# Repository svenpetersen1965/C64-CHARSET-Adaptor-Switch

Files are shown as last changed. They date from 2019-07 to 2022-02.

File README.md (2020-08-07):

# C64-CHARSET-Adaptor-Switch
An Adaptor for the Character ROM of the Commodore C64 (2332 = 4k). It accepts EPROMs of the types 27C64, 27C128, 27C256 and 27C512.

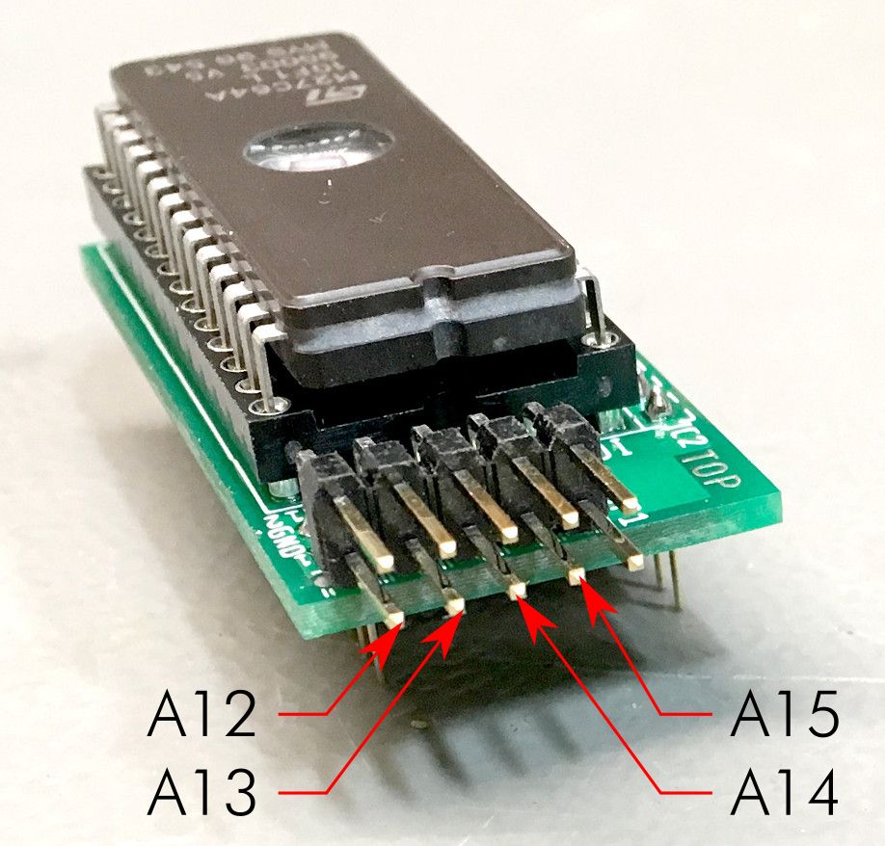
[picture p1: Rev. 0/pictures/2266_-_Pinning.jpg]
C64 charset adaptor/switch


The charcter sets can be selected by jumper or by a microcontroller circuit like an arduino or the keyboard controlled kernal switch: https://github.com/svenpetersen1965/C64-Keyboard-Controlled-Kernal-Switch
# Calculation of the BOM v0.0 prices
The prices were calculated June 9th, 2020. The total costs for the components and PCB are 3.80€, which does not include and shipping fees.

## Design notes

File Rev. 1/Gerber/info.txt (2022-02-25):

      
       Board: C64_CHARSETSw_4k
       Rev.:  1
  
       Files:
       ======
  
       All Gerber files are generated in extended gerber format (RS274X)
       *.TOP        : Film top copper
       *.BOT        :  -"- bottom copper
       *.STC        :  -"- top soldermask 
       *.STS        :  -"- bottom soldermask
       *.PLC        :  -"- silk screen top
       *.PLS        :  -"- silk screen bottom
       *.CRC        :  -"- cream top
       *.DK         : Drills plated Through (Excellon)
       *.NDK        : Drills not plated Through (Excellon)
       *.OUT        : Board outline

       Board Size:
       ===========
       Length     :   45.0 mm
       Width      :   22.0 mm
       Thickness  :   1.6 mm
       Material   :   FR 4
       Copper     :   35 um
       Surface    :   HASL
       
       Remarks:
       ========

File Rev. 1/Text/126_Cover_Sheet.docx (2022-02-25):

Project Documentation

C64 CHARSET-Adaptor/Switch

Project number: 126

Revision: 1

Date: 15.02.2021


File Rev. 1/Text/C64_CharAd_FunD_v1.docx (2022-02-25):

C64 CHARSET-Adaptor/Switch Rev. 1

Functional Description

IC2 is not an actual IC, these are the precision round pin contacts on the solder side of the module, that fit into the Character ROM socket on the C64 mainboard. The signals A0…A11 are connected to the address bus, D0…D7 are connected to the data bus. The chip select signal is connected to the C64 signal, which selects the character rom at the addresses 0xD000 - 0xDFFF.

IC1 is the EPROM, which is here represented by a 27C512 (other types are possible, see the document 126-6-01-**/Module Description).

The chip select signal is connected to pin 22, the enable signal is permanently LOW.

R1 – R4 are pull-up resistors. The desired character set can be either jumpered at JP1 or selected by a micro controller, which is connected to the same pin header.

C64_CharAd_FunD_v1.docx 25.02.2022 10:58 Drafted by Sven Petersen Page 2 of 2 Doc.-No.: 000-6-00-00

C64_CharAd_FunD_v1.docx 25.02.2022 10:58 Drafted by Sven Petersen Page 1 of 1 Doc.-No.: 126-6-02-01

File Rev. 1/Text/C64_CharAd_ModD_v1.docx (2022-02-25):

C64 CHARSET-Adaptor/Switch Rev. 1

Module Description

# Introduction

The board serves for adapting the CHARACTER ROM U5 (type 2332) to a 27C512 (or 27C256, 27C128, 27C64) EPROM. The pin out of both ICs are slightly different and need adaptation. Furthermore, it allows to access (up to 16) different character sets, which can be selected via the pin-header on the module.

The CHARSET-Adaptor/Switch is suitable to work together with the Keyboard Controlled Kernal Switch (Project Number 128).

This pin-header is connected in a way, that the selection can either be accomplished with standard 2.54mm jumper bridges, DIP-switches, hex-encoding switches or a microcontroller like an Arduino etc.

Signal | Pin | Pin | Signal
A12 | 1 | 2 | GND
A13 | 3 | 4 | GND
A14 | 5 | 6 | GND
A15 | 7 | 8 | GND
+5V | 9 | 10 | n.c.

Table 1: Jumper (JP1) for Bank Selection

The +5V pins are to provide supply voltage to a microcontroller.


Figure 1: Address pins of JP1

# Bank Selection

The desired CHARACTER SET is selected at JP1. For the pinout refer to Table 1. The jumper is installed (vertically) in a way, that it connects the address line with the GND potential.

A15 | A14 | A13 | A12 | 4k Block | | Addr. Offset
set | set | set | set | | #0 | 0x0000
set | set | set | open | | #1 | 0x1000
set | set | open | set | | #2 | 0x2000
set | set | open | open | | #3 | 0x3000
set | open | set | set | | #4 | 0x4000
set | open | set | open | | #5 | 0x5000
set | open | open | set | | #6 | 0x6000
set | open | open | open | | #7 | 0x7000
open | set | set | set | | #8 | 0x8000
open | set | set | open | | #9 | 0x9000
open | set | open | set | | #10 | 0xA000
open | set | open | open | | #11 | 0xB000
open | open | set | set | | #12 | 0xC000
open | open | set | open | | #13 | 0xD000
open | open | open | set | | #14 | 0xE000
open | open | open | open | | #15 | 0xF000

Table 2: Selection of EPROM memory blocks

A set jumper corresponds to a LOW level (binary 0), an open jumper to a HIGH level. Do not confuse the C64 memory address and the EPROM memory address. They have the address Bit A0 to A11 in common, but the rest is different. Each of the 4k blocks appears between address $D000 and $DFFF of the C64.

# Dimensions

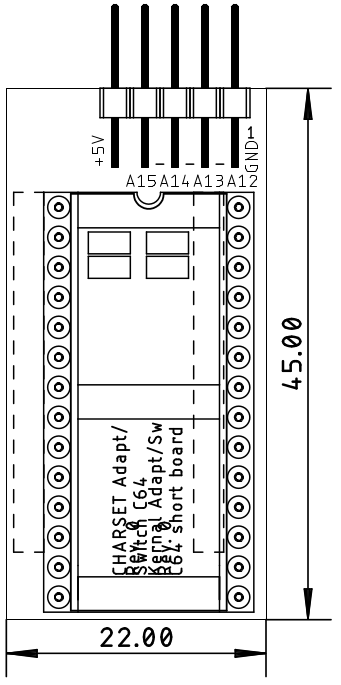
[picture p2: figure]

Figure 2: Dimensions of the Character ROM Adaptor/Switch

# Compatibility of EPROMs

Although a 27C512 type EPROM is recommended, other types of EPROMs can be installed:

EPROM | Size | Capacity
27C64 | 8k | 2x Character Sets
27C128 | 16k | 4x Character Sets
27C256 | 32k | 8x Character Sets
27C512 | 64k | 16x Character Sets

Table 3: Capacity of EPROM types

Those EPROMs are pin compatible, the jumpers, that have no function, due to the size, have to stay open.

EPROM | Size | A15 | A14 | A13 | A12
27C512 | 64kx8 | ☑ | ☑ | ☑ | ☑
27C256 | 32kx8 | open | ☑ | ☑ | ☑
27C128 | 16kx8 | open | open | ☑ | ☑
27C64 | 8kx8 | open | open | open | ☑

Table 4: Settings per EPROM type

☑: The jumper can be open or closed, depending on the desired selection.

In case Vpp is located at a dedicated pin (pin 1), A15 has no effect anymore. A HIGH level is recommended, the corresponding jumper is open. The /PGM Pin should be set HIGH, this is accomplished by an open jumper for A14.

27C64
| 27C128
| | 27C256
| | | 27C512
| | | | SOCKET
Vpp | Vpp | Vpp | A15 | 1 | A15 | VCC | 28 | VCC | VCC | VCC | VCC
A12 | A12 | A12 | A12 | 2 | A12 | A14 | 27 | A14 | A14 | /PGM | /PGM
A7 | A7 | A7 | A7 | 3 | A7 | A13 | 26 | A13 | A13 | A13 | n.c.
A6 | A6 | A6 | A6 | 4 | A6 | A8 | 25 | A8 | A8 | A8 | A8
A5 | A5 | A5 | A5 | 5 | A5 | A9 | 24 | A9 | A9 | A9 | A9
A4 | A4 | A4 | A4 | 6 | A4 | A11 | 23 | A11 | A11 | A11 | A11
A3 | A3 | A3 | A3 | 7 | A3 | /OE | 22 | /G/Vpp | /G | /G | /G
A2 | A2 | A2 | A2 | 8 | A2 | A10 | 21 | A10 | A10 | A10 | A10
A1 | A1 | A1 | A1 | 9 | A1 | GND | 20 | /E | /E | /E | /E
A0 | A0 | A0 | A0 | 10 | A0 | D7 | 19 | D7 | D7 | D7 | D7
D0 | D0 | D0 | D0 | 11 | D0 | D6 | 18 | D6 | D6 | D6 | D6
D1 | D1 | D1 | D1 | 12 | D1 | D5 | 17 | D5 | D5 | D5 | D5
D2 | D2 | D2 | D2 | 13 | D2 | D4 | 16 | D4 | D4 | D4 | D4
GND | GND | GND | GND | 14 | GND | D3 | 15 | D3 | D3 | D3 | D3

Table 5: EPROM pin compatibility

# Programming instructions

Character sets can be found here:

http://www.zimmers.net/anonftp/pub/cbm/firmware/computers/c64/index.html or elsewhere. For instructions on setting up a complete multiple character ROM image, please refer to

https://github.com/svenpetersen1965/C64-Kernal-Adapter-Switch-Long-Board/blob/master/Rev.%200/pdf/C64_KernalSw_8k_v0.pdf

The description is about how to create a multiple Kernal ROM image, a multiple Character ROM image works pretty similar, except the size is only 4kB.

# Revision History

## Rev. 0

Prototype, fully functional.

## Rev. 1

Changed JP1 (solder pads, no +5V at pin 10/pin 9 only)

C64_CharAd_ModD_v1.docx 25.02.2022 10:59 Drafted by Sven Petersen Page 2 of 2 Doc.-No.: 126-6-01-01

C64_CharAd_ModD_v1.docx 25.02.2022 10:59 Drafted by Sven Petersen Page 1 of 1 Doc.-No.: 000-6-00-00

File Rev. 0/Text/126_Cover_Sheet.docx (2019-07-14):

Project Documentation

C64 CHARSET-Adaptor/Switch

Project number: 126

Revision: 0

Date: 15.05.2019


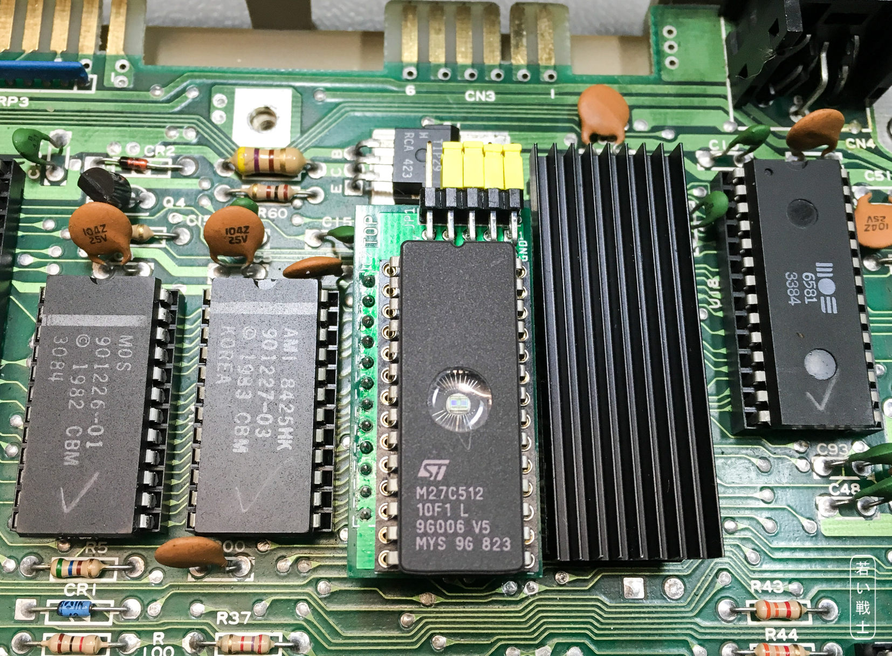
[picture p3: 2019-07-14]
Rev. 1/pictures/2268_-_CharAd_ASSY250425.JPG

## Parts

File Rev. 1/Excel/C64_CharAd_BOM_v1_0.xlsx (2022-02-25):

C64 CHARSET-Adaptor/Switch Rev. 1
Bill of Material Rev. 1.0
Pos. | Qty | Value | Footprint | Ref.-No. | Comment
1 | 1 | 126-2-01-01 | 2 Layer | PCB Rev. 1 | 2 layer, Cu 35µ, HASL, 45mm x 22mm, 1.6mm FR4
2 | 1 | 2x05pin/90° | 2X05_90_SERIES_088 | JP1 | 90° pin header, 2.54mm pitch. E.g. Reichelt MPE 088-2-010
3 | 4 | Jumper | 2.54mm | (JP1) | Jumpers for address selection (in case it is intended to jumper the kenal selection)
4 | 4 | 10k | 0805 | R1, R2, R3, R3 | SMD resistor
5 | 1 | two Pinstrip, precision round pins, cut to 12 pins length | DIL24_SOCKET | IC2 | Precision Round pins mandatory! E.g. Reichelt BKL 10120540 or
 |  |  |  |  | 10PCS Single Row 40Pin 2.54mm Round Male Pin Header machined (https://www.ebay.de/itm/10PCS-Single-Row-40Pin-2-54mm-Round-Male-Pin-Header-machined/281821698031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)
6 | 1 | M27C512 | DIL28-6 | IC1 | EPROM 200ns or faster recommended, alternative sizes: 27C64, 27C128, 27C256 possible
7 | 1 | DIP28 socket | DIL28-6 | (IC1) | Precision round pin is recommended

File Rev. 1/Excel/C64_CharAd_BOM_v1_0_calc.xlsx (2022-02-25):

C64 CHARSET-Adaptor/Switch Rev. 1
Bill of Material Rev. 1.0
Pos. | Qty | Value | €/ea | € | Comment
1 | 1 | 126-2-01-01 | 1.00 € | 1.00 € | 2 layer, Cu 35µ, HASL, 45mm x 22mm, 1.6mm FR4
2 | 1 | 2x05pin/90° | 0.22 € | 0.22 € | 90° pin header, 2.54mm pitch. E.g. Reichelt MPE 088-2-010
3 | 4 | Jumper | 0.02 € | 0.08 € | Jumpers for address selection (in case it is intended to jumper the kenal selection)
4 | 4 | 10k | 0.02 € | 0.08 € | SMD resistor
5 | 1 | two Pinstrip, precision round pins, cut to 12 pins length | 1.99 € | 1.99 € | Precision Round pins mandatory! E.g. Reichelt BKL 10120540 or
 |  |  |  | 0.00 € | 10PCS Single Row 40Pin 2.54mm Round Male Pin Header machined (https://www.ebay.de/itm/10PCS-Single-Row-40Pin-2-54mm-Round-Male-Pin-Header-machined/281821698031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)
6 | 0 | M27C512 | 0.00 € | 0.00 € | EPROM 200ns or faster recommended, alternative sizes: 27C64, 27C128, 27C256 possible
7 | 1 | DIP28 socket | 0.43 € | 0.43 € | Precision round pin is recommended
8 |  |  | Total | 3.80 €

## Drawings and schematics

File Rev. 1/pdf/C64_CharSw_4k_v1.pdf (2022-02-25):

# Project Documentation

## C64 CHARSET-Adaptor/Switch

## Project number: 126

## Revision: 1

## Date: 15.02.2021

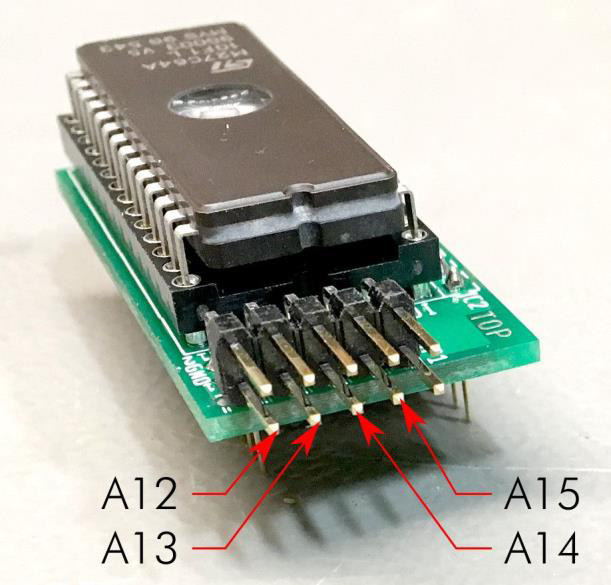
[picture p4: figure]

C64_CharAd_ModD_v1.docx | | 25.02.2022 10:59
Drafted by Sven Petersen | Page 1 of 4 | Doc.-No.: 126-6-01-01

### C64 CHARSET-Adaptor/Switch Rev. 1

### Module Description

## Introduction

The board serves for adapting the CHARACTER ROM U5 (type 2332) to a 27C512 (or 27C256, 27C128, 27C64) EPROM. The pin out of both ICs are slightly different and need adaptation. Furthermore, it allows to access (up to 16) different character sets, which can be selected via the pin-header on the module.

The CHARSET-Adaptor/Switch is suitable to work together with the Keyboard Controlled Kernal Switch (Project Number 128).

This pin-header is connected in a way, that the selection can either be accomplished with standard 2.54mm jumper bridges, DIP-switches, hex-encoding switches or a microcontroller like an Arduino etc.

Signal Pin | Pin Signal
A12 | 1 | 2 | GND
A13 | 3 | 4 | GND
A14 | 5 | 6 | GND
A15 | 7 | 8 | GND
+5V | 9 | 10 | n.c.
Table 1: Jumper (JP1) for Bank Selection

The +5V pins are to provide supply voltage to a microcontroller.

Figure 1: Address pins of JP1

## Bank Selection

The desired CHARACTER SET is selected at JP1. For the pinout refer to Table 1. The jumper is installed (vertically) in a way, that it connects the address line with the GND potential.

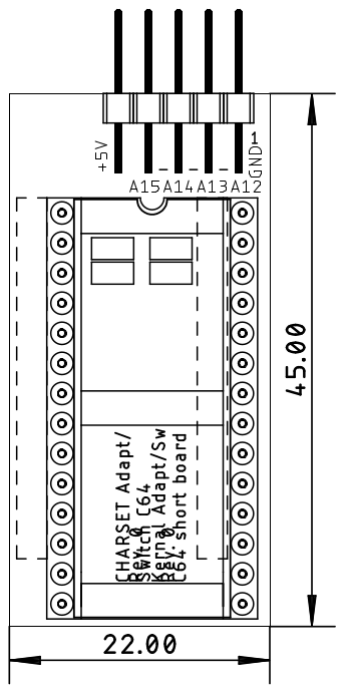
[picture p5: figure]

C64_CharAd_ModD_v1.docx | | 25.02.2022 10:59
Drafted by Sven Petersen | Page 2 of 4 | Doc.-No.: 126-6-01-01
A15 | A14 | A13 | A12 | 4k Block | Addr. Offset
set | set | set | set | #0 | 0x0000
set | set | set | open | #1 | 0x1000
set | set | open | set | #2 | 0x2000
set | set | open | open | #3 | 0x3000
set | open | set | set | #4 | 0x4000
set | open | set | open | #5 | 0x5000
set | open | open | set | #6 | 0x6000
set | open | open | open | #7 | 0x7000
open | set | set | set | #8 | 0x8000
open | set | set | open | #9 | 0x9000
open | set | open | set | #10 | 0xA000
open | set | open | open | #11 | 0xB000
open | open | set | set | #12 | 0xC000
open | open | set | open | #13 | 0xD000
open | open | open | set | #14 | 0xE000
open | open | open | open | #15 | 0xF000
Table 2: Selection of EPROM memory blocks

A set jumper corresponds to a LOW level (binary 0), an open jumper to a HIGH level. Do not confuse the C64 memory address and the EPROM memory address. They have the address Bit A0 to A11 in common, but the rest is different. Each of the 4k blocks appears between address $D000 and $DFFF of the C64.

## Dimensions

Figure 2: Dimensions of the Character ROM Adaptor/Switch

C64_CharAd_ModD_v1.docx | | 25.02.2022 10:59
Drafted by Sven Petersen | Page 3 of 4 | Doc.-No.: 126-6-01-01

## Compatibility of EPROMs

Although a 27C512 type EPROM is recommended, other types of EPROMs can be installed:

EPROM | Size | Capacity
27C64 | 8k | 2x Character Sets
27C128 | 16k | 4x Character Sets
27C256 | 32k | 8x Character Sets
27C512 | 64k | 16x Character Sets
Table 3: Capacity of EPROM types

Those EPROMs are pin compatible, the jumpers, that have no function, due to the size, have to stay open.

EPROM | Size | A15 | A14 | A13 | A12
27C512 | 64kx8 | ☑ | ☑ | ☑ | ☑
27C256 | 32kx8 | open | ☑ | ☑ | ☑
27C128 | 16kx8 | open | open | ☑ | ☑
27C64 | 8kx8 | open | open | open | ☑
Table 4: Settings per EPROM type

☑: The jumper can be open or closed, depending on the desired selection.

In case Vpp is located at a dedicated pin (pin 1), A15 has no effect anymore. A HIGH level is recommended, the corresponding jumper is open. The /PGM Pin should be set HIGH, this is accomplished by an open jumper for A14.
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

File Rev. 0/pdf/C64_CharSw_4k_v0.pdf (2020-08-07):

# Project Documentation

## C64 CHARSET-Adaptor/Switch

## Project number: 126

## Revision: 0

## Date: 15.05.2019

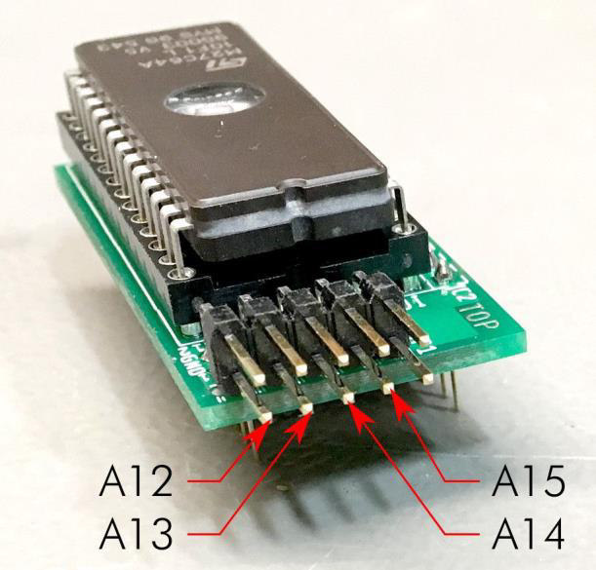
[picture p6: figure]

C64_CharAd_ModD_v0.docx | | 14.07.2019 10:30
Drafted by Sven Petersen | Page 1 of 4 | Doc.-No.: 126-6-01-00

### C64 CHARSET-Adaptor/Switch Rev. 0

### Module Description

## Introduction

The board serves for adapting the CHARACTER ROM U5 (type 2332) to a 27C512 (or 27C256, 27C128, 27C64) EPROM. The pin out of both ICs are slightly different and need adaptation. Furthermore, it allows to access (up to 16) different character sets, which can be selected via the pin-header on the module.

The CHARSET-Adaptor/Switch is suitable to work together with the Keyboard Controlled Kernal Switch (Project Number 128).

This pin-header is connected in a way, that the selection can either be accomplished with standard 2.54mm jumper bridges, DIP-switches, hex-encoding switches or a microcontroller like an Arduino etc.

Signal Pin | Pin Signal
A12 | 1 | 2 | GND
A13 | 3 | 4 | GND
A14 | 5 | 6 | GND
A15 | 7 | 8 | GND
+5V | 9 | 10 | +5V
Table 1: Jumper (JP1) for Bank Selection

The +5V pins are to provide supply voltage to a microcontroller.

Figure 1: Address pins of JP1

## Bank Selection

The desired CHARACTER SET is selected at JP1. For the pinout refer to Table 1. The jumper is installed (vertically) in a way, that it connects the address line with the GND potential.


C64_CharAd_ModD_v0.docx | | 14.07.2019 10:30
Drafted by Sven Petersen | Page 2 of 4 | Doc.-No.: 126-6-01-00
A15 | A14 | A13 | A12 | 4k Block | Addr. Offset
set | set | set | set | #0 | 0x0000
set | set | set | open | #1 | 0x1000
set | set | open | set | #2 | 0x2000
set | set | open | open | #3 | 0x3000
set | open | set | set | #4 | 0x4000
set | open | set | open | #5 | 0x5000
set | open | open | set | #6 | 0x6000
set | open | open | open | #7 | 0x7000
open | set | set | set | #8 | 0x8000
open | set | set | open | #9 | 0x9000
open | set | open | set | #10 | 0xA000
open | set | open | open | #11 | 0xB000
open | open | set | set | #12 | 0xC000
open | open | set | open | #13 | 0xD000
open | open | open | set | #14 | 0xE000
open | open | open | open | #15 | 0xF000
Table 2: Selection of EPROM memory blocks

A set jumper corresponds to a LOW level (binary 0), an open jumper to a HIGH level. Do not confuse the C64 memory address and the EPROM memory address. They have the address Bit A0 to A11 in common, but the rest is different. Each of the 4k blocks appears between address $D000 and $DFFF of the C64.

## Dimensions

Figure 2: Dimensions of the Character ROM Adaptor/Switch

C64_CharAd_ModD_v0.docx | | 14.07.2019 10:30
Drafted by Sven Petersen | Page 3 of 4 | Doc.-No.: 126-6-01-00

## Compatibility of EPROMs

Although a 27C512 type EPROM is recommended, other types of EPROMs can be installed:

EPROM | Size | Capacity
27C64 | 8k | 2x Character Sets
27C128 | 16k | 4x Character Sets
27C256 | 32k | 8x Character Sets
27C512 | 64k | 16x Character Sets
Table 3: Capacity of EPROM types

Those EPROMs are pin compatible, the jumpers, that have no function, due to the size, have to stay open.

EPROM | Size | A15 | A14 | A13 | A12
27C512 | 64kx8 | ☑ | ☑ | ☑ | ☑
27C256 | 32kx8 | open | ☑ | ☑ | ☑
27C128 | 16kx8 | open | open | ☑ | ☑
27C64 | 8kx8 | open | open | open | ☑
Table 4: Settings per EPROM type

☑: The jumper can be open or closed, depending on the desired selection.

In case Vpp is located at a dedicated pin (pin 1), A15 has no effect anymore. A HIGH level is recommended, the corresponding jumper is open. The /PGM Pin should be set HIGH, this is accomplished by an open jumper for A14.
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

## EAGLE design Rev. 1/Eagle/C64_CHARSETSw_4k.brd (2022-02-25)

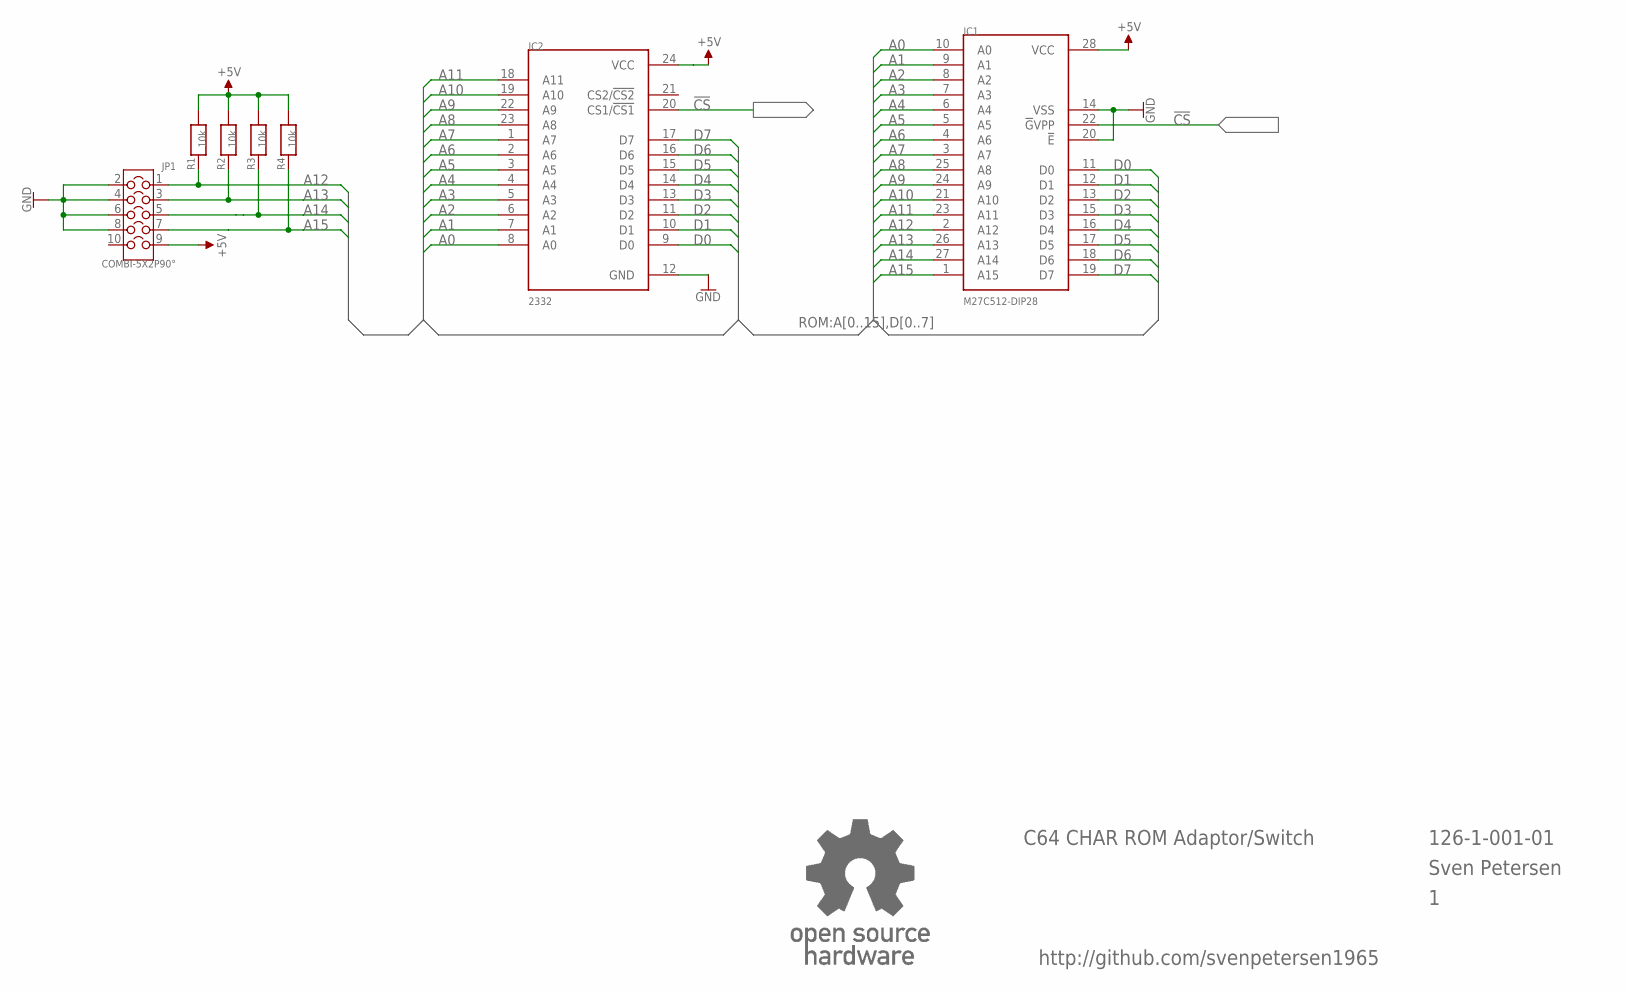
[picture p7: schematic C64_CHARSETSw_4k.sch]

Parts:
IC1: M27C512-DIP28; DIL28-6
IC2: 2332; DIL24_SOCKET
JP1: COMBI-5X2P90°; COMBI-5X2-90
R1, R2, R3, R4: 10k; 0805
U$6: OPEN_SOURCE_HW; OPENHW

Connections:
!CS: IC1.22 (!G!VPP), IC2.20 (CS1/!CS1)
+5V: IC1.28 (VCC), IC2.24 (VCC), JP1.9, R1.2, R2.2, R3.2, R4.2
A0: IC1.10 (A0), IC2.8 (A0)
A1: IC1.9 (A1), IC2.7 (A1)
A2: IC1.8 (A2), IC2.6 (A2)
A3: IC1.7 (A3), IC2.5 (A3)
A4: IC1.6 (A4), IC2.4 (A4)
A5: IC1.5 (A5), IC2.3 (A5)
A6: IC1.4 (A6), IC2.2 (A6)
A7: IC1.3 (A7), IC2.1 (A7)
A8: IC1.25 (A8), IC2.23 (A8)
A9: IC1.24 (A9), IC2.22 (A9)
A10: IC1.21 (A10), IC2.19 (A10)
A11: IC1.23 (A11), IC2.18 (A11)
A12: IC1.2 (A12), JP1.1, R1.1
A13: IC1.26 (A13), JP1.3, R2.1
A14: IC1.27 (A14), JP1.5, R3.1
A15: IC1.1 (A15), JP1.7, R4.1
D0: IC1.11 (D0), IC2.9 (D0)
D1: IC1.12 (D1), IC2.10 (D1)
D2: IC1.13 (D2), IC2.11 (D2)
D3: IC1.15 (D3), IC2.13 (D3)
D4: IC1.16 (D4), IC2.14 (D4)
D5: IC1.17 (D5), IC2.15 (D5)
D6: IC1.18 (D6), IC2.16 (D6)
D7: IC1.19 (D7), IC2.17 (D7)
GND: IC1.14 (VSS), IC1.20 (!E), IC2.12 (GND), JP1.2, JP1.4, JP1.6, JP1.8

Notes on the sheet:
126-1-001-01
Sven Petersen
C64 CHAR ROM Adaptor/Switch
http://github.com/svenpetersen1965

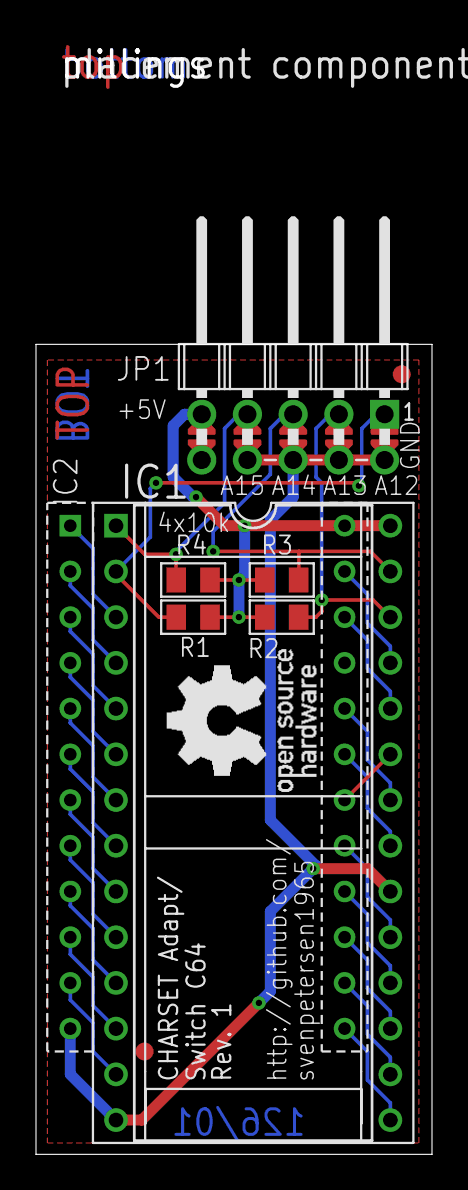
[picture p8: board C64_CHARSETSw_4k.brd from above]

Board: 2 copper layers, 22.0 x 45.0 mm, 14 parts (1 on the bottom side), 27 nets.

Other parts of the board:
U$11: SVEN_TAG
U$16: GS28P
U$17, U$18: SMD_REF_R1MM
U$19: 2LAYER
U$20: PCB-TITLE/

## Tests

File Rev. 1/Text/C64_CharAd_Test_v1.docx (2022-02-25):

C64 CHARSET-Adaptor/Switch Rev. 1

Testing

The module was tested on a C64 Mainboard ASSY250425. The test was conducted with various character sets, which were obtained from the internet. The character sets were selected by jumpering JP1.

The EPROM, which was used for the test was ST M27C512-10F1 (100ns).

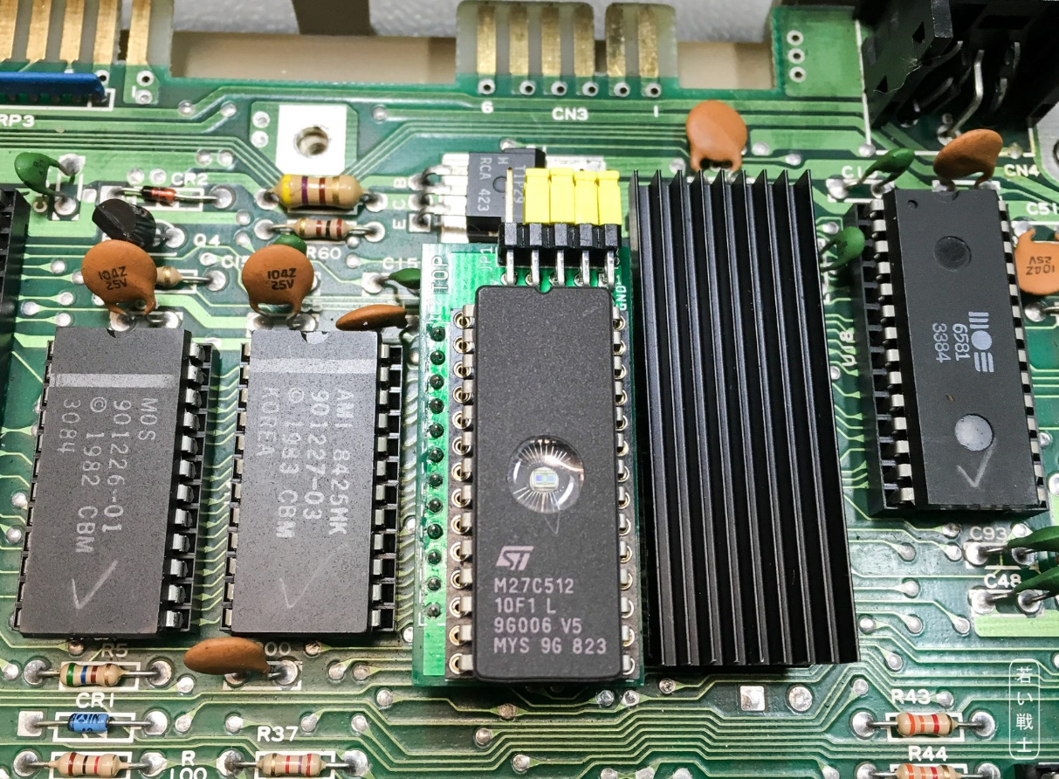
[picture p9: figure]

Figure 1: The module installed on an ASSY 250425 mainboard

It was required to slightly bend a capacitor away from the socket. Other than that, no collisions with other components have occurred. The module was sitting firmly in the socket.

After switching on the C64, the selected character sets worked properly. The selection was changed by modifying the jumpering of the pin header JP1.

Conclusion: The C64 CHARSET-Adaptor/Switch is fully functional.

# Rev. 1 Due to the minor changes, Rev. 1 is not yet tested.

C64_CharAd_Test_v1.docx 25.02.2022 10:59 Drafted by Sven Petersen Page 2 of 2 Doc.-No.: 126-6-03-01

C64_CharAd_Test_v1.docx 25.02.2022 10:59 Drafted by Sven Petersen Page 1 of 1 Doc.-No.: 000-6-00-00

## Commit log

2020-06-09 Calculation of BOM v0.0
    [C64_CharAd_BOM_v0_0_calc.xlsx]
2020-08-07 Silk Screen Revision
    [C64_CHARSETSw_4k.brd, C64_CHARSETSw_4k.sch]
2022-02-25 Rev. 1 released
    [C64_CHARSETSw_4k.brd, C64_CHARSETSw_4k.sch, C64_CharAd_BOM_v1_0.xlsx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]
